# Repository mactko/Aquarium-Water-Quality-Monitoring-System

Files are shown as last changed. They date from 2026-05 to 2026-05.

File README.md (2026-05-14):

# 🐠 Aquarium Water Quality Monitor

An embedded system for continuous, automated monitoring and maintenance of aquarium water quality — measuring temperature and turbidity, controlling a pump/filter, and pushing data to the cloud.

---

## ✨ What It Does

| Feature | Details |
|---|---|
| 🌡️ Temperature | DS18B20 sensor via 1-Wire |
| 💧 Turbidity | SEN0189 analog sensor + median/deadzone filtering |
| ⚙️ Pump Control | Auto PWM regulation based on turbidity |
| 📡 Connectivity | Wi-Fi with auto-reconnect (FreeRTOS) |
| ☁️ Cloud | Sensor data → Azure Table Storage via MQTT over TLS |

---

## 🔧 Hardware

- **ESP32-DevKitC** — main microcontroller (Wi-Fi, dual-core)
- **DS18B20** — waterproof digital temperature sensor
- **SEN0189** — analog turbidity sensor (DF Robot)
- **DC water pump** — MOSFET-switched, PWM-controlled
- **4-stage filter** — mechanical filtration driven by the pump
- **12V adapter** + **5V regulator** — power supply chain

---

## 🖥️ System Overview

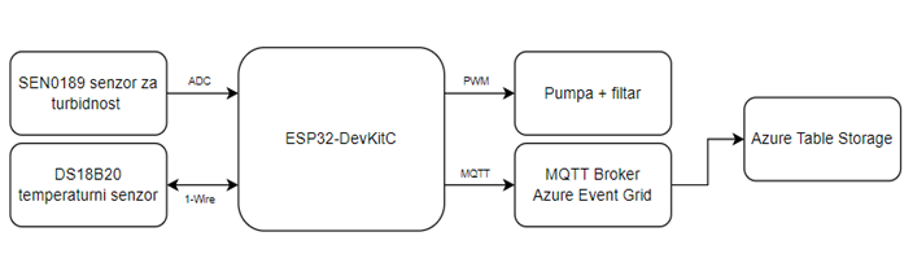
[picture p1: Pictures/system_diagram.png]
System Block Diagram


---

## ☁️ Cloud Architecture

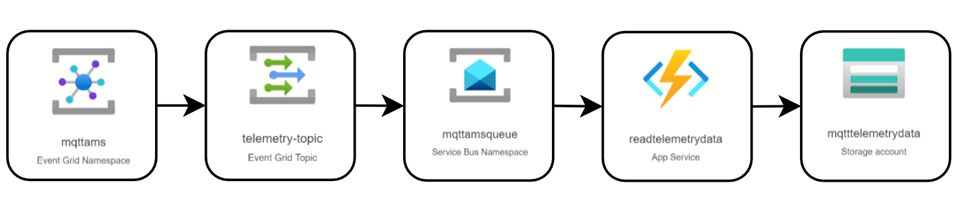
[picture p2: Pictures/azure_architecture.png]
Azure Cloud Architecture


```
ESP32 → MQTT/TLS → Azure Event Grid → Service Bus Queue → Function App → Table Storage
```

Telemetry is published every 60 seconds in the format:
```
<temperature>|<turbidity>    e.g. 27.500000|234
```

---

## 🚀 Quick Start

1. **Install** [ESP-IDF v5.x](https://docs.espressif.com/projects/esp-idf/en/stable/esp32/get-started/)
2. **Provision Azure** — Event Grid Namespace, Service Bus, Function App, Table Storage
3. **Generate TLS certs** with OpenSSL and place them in `Code/ESP/main/certificates/` and `Code/ESP/main/keys/`
4. **Configure** Wi-Fi credentials and MQTT broker via `idf.py menuconfig`
5. **Build & flash:**
```bash
cd "Code/ESP"
idf.py build
idf.py -p <PORT> flash monitor
```

---

## 📁 Project Structure

```
├── Code/
│   ├── ESP/               # ESP32 firmware (ESP-IDF)
│   │   ├── components/    # Drivers: Wi-Fi, DS18B20, pump, turbidity
│   │   └── main/          # App entry point + TLS certs/keys
│   └── Azure/             # Function App — Service Bus consumer → Table Storage
├── 3d models/             # 3D-printed enclosure
├── Pictures/              # Images and diagrams
└── README.md
```

---

## 🧪 Test Results

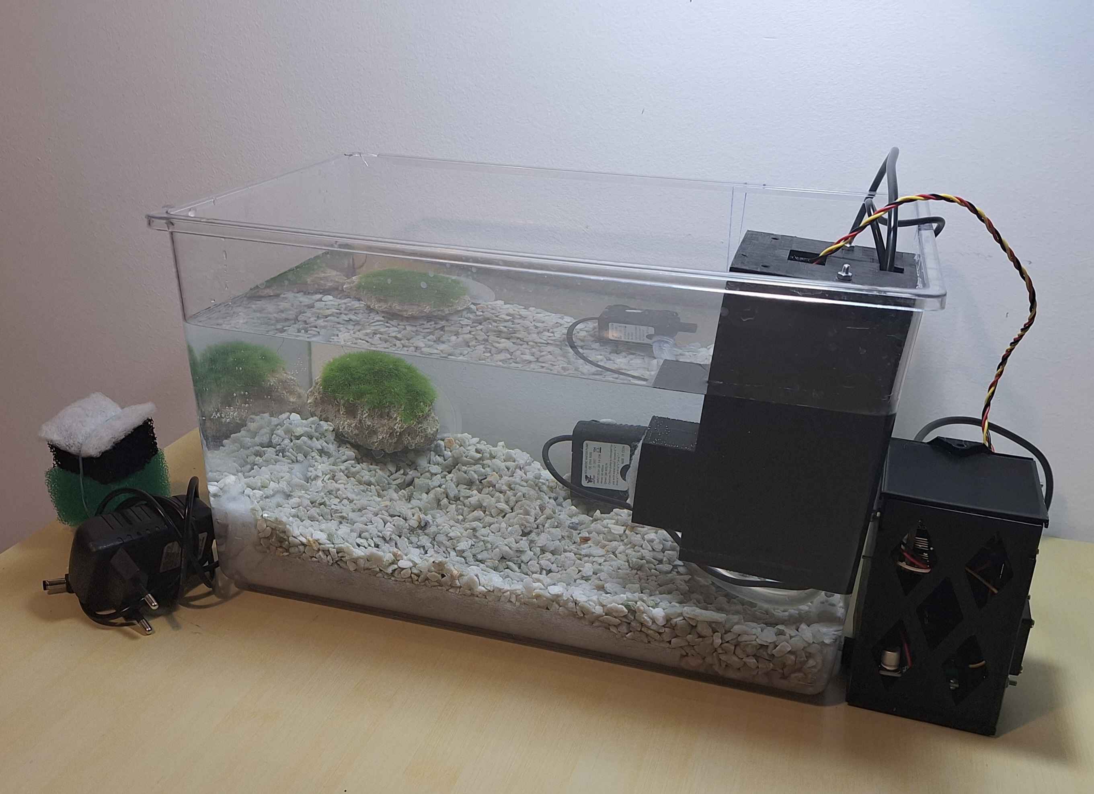
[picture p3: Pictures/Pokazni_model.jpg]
Test Setup


Tested continuously for **12 hours** on a small acrylic aquarium:

- ✅ Data successfully uploaded every 60 s throughout
- ✅ Auto-recovery from Wi-Fi and MQTT disconnections
- ✅ Median + deadzone filter effectively suppressed sensor noise
- ⚠️ Gradual turbidity drift due to sedimentation — periodic sensor cleaning recommended

---

## 🛠️ Common Issues

| Issue | Fix |
|---|---|
| Won't connect to Wi-Fi | Check SSID/password in config |
| MQTT refused | Regenerate certs; re-register device in Azure |
| Turbidity reads 0 | Check wiring to GPIO33; confirm sensor is submerged |
| Temperature reads 85°C | Check pull-up resistor on 1-Wire data line |
| No data in Table Storage | Check Service Bus backlog; review Function App logs |

---

*Developed as an undergraduate thesis at the Faculty of Electrical Engineering and Computing, University of Zagreb.*

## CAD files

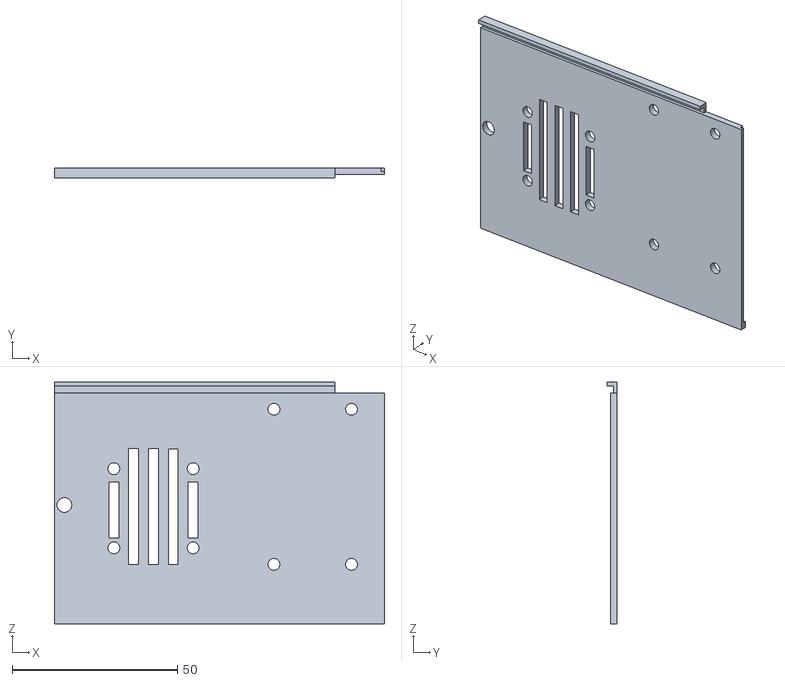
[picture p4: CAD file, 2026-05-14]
3d models/Control unit/Left_panel.stl
100.0 x 3.00 x 73.2

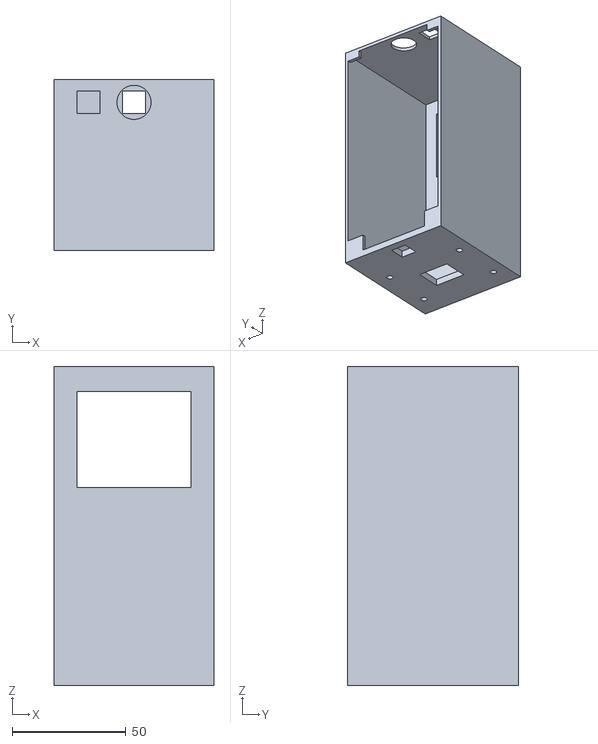
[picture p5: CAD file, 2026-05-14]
3d models/Housing/Housing.stl
70.0 x 75.0 x 140.0

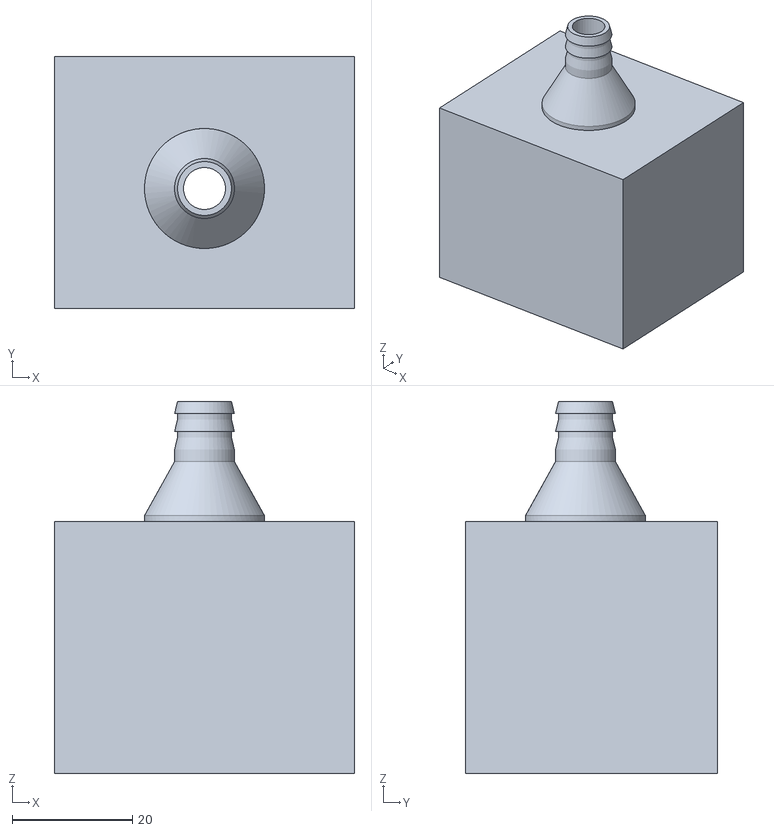
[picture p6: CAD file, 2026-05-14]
3d models/Housing/Filter.stl
50.0 x 42.0 x 62.0

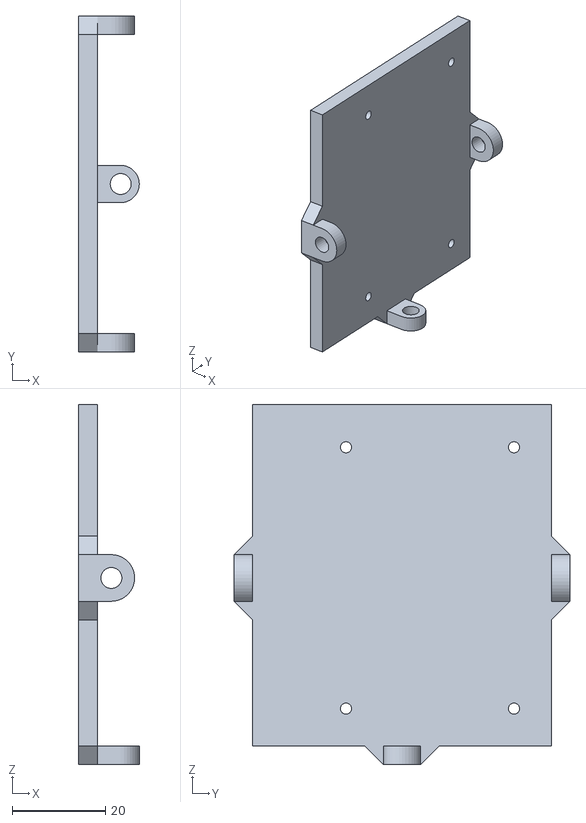
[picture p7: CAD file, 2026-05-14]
3d models/Control unit/Bottom_panel.stl
13.0 x 72.0 x 77.2

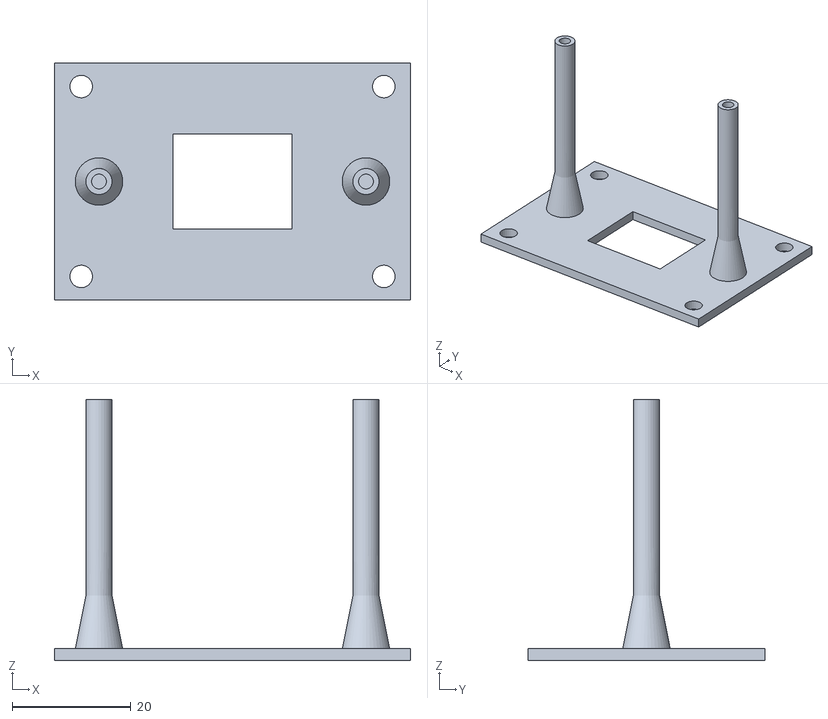
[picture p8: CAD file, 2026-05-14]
3d models/Housing/SEN0189_sensor_holder.stl
60.0 x 40.0 x 44.0

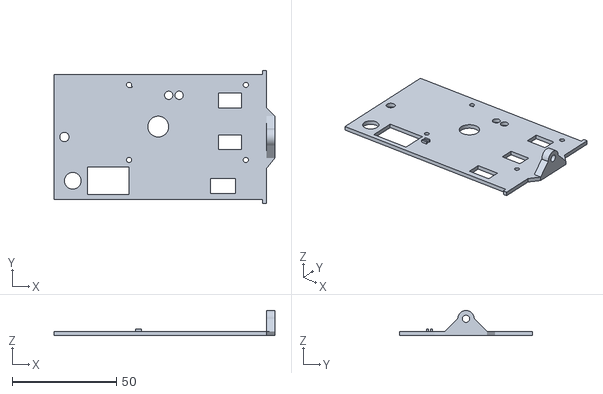
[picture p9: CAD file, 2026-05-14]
3d models/Control unit/Back_panel.stl
106.0 x 64.0 x 12.0

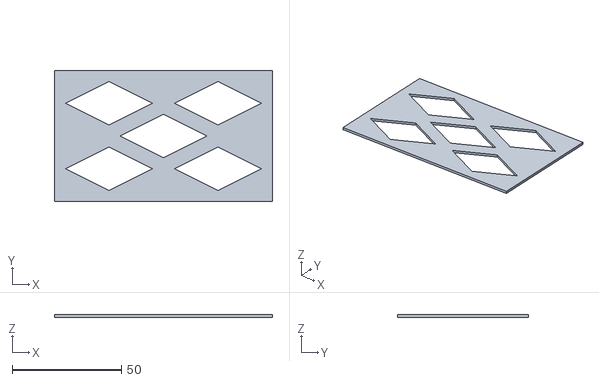
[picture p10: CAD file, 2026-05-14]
3d models/Control unit/Forward_panel.stl
100.0 x 60.0 x 1.20

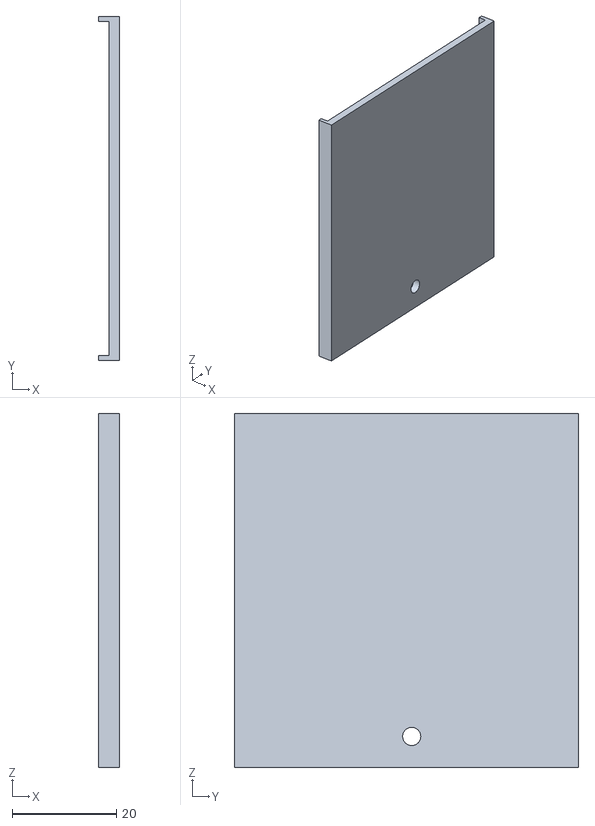
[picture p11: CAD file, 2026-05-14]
3d models/Control unit/Top_panel.stl
4.00 x 66.0 x 68.0

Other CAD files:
3d models/Control unit/Right_panel.stl

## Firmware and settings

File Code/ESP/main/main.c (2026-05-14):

#include "main.h"

static float temperature_data = 0;
static int turbidity_data = 0;

static const char *TAG = "MQTTS";

esp_mqtt_client_handle_t mqtt_client;

volatile uint8_t brokerC = 0;

extern const uint8_t brokerCert_pem_start[] asm("_binary_brokerCert_pem_start");
extern const uint8_t brokerCert_pem_end[] asm("_binary_brokerCert_pem_end");

extern const uint8_t deviceCert_pem_start[] asm("_binary_deviceCert_pem_start");
extern const uint8_t deviceCert_pem_end[] asm("_binary_deviceCert_pem_end");

extern const uint8_t deviceCert_key_start[] asm("_binary_deviceCert_key_start");
extern const uint8_t deviceCert_key_end[] asm("_binary_deviceCert_key_end");

void mqtt_event_handler(void *handler_args, esp_event_base_t base, int32_t event_id, void *event_data)
{
    esp_mqtt_event_handle_t event = event_data;

    switch ((esp_mqtt_event_id_t)event_id) {
    case MQTT_EVENT_CONNECTED:
        ESP_LOGI(TAG, "Connected to broker");
        esp_mqtt_client_publish(mqtt_client, "telemetry/my-device/temperature", "0.0|0", 0, 1, 0); 
        break;
    case MQTT_EVENT_DISCONNECTED:
        ESP_LOGI(TAG, "MQTT_EVENT_DISCONNECTED");
        break;
    case MQTT_EVENT_SUBSCRIBED:
        ESP_LOGI(TAG, "MQTT_EVENT_SUBSCRIBED, msg_id=%d", event->msg_id);
        break;
    case MQTT_EVENT_UNSUBSCRIBED:
        ESP_LOGI(TAG, "MQTT_EVENT_UNSUBSCRIBED, msg_id=%d", event->msg_id);
        break;
    case MQTT_EVENT_PUBLISHED:
        ESP_LOGI(TAG, "Recieved PUBACK/PUBCOMP -> Test reached broker");
        brokerC = 1;
        break;
    case MQTT_EVENT_DATA:
        ESP_LOGI(TAG, "MQTT_EVENT_DATA");
        break;
    case MQTT_EVENT_ERROR:
        ESP_LOGI(TAG, "MQTT_EVENT_ERROR");  
        brokerC = 0;  
        break;
    default:
        ESP_LOGI(TAG, "Other event id:%d", event->event_id);
        break;
    }
}

esp_err_t mqtt_app_start(void)
{
    const esp_mqtt_client_config_t mqtt_cfg = {
        .broker = {
            .address = {
                .uri = "uri",
            },
            .verification = {
                .certificate = (char *)brokerCert_pem_start,
                .certificate_len = GetBrokerCertLength()
            },
        },
        .credentials = {
            .username = "ESP32-node",
            .authentication = {
                .certificate = (char *)deviceCert_pem_start,
                .certificate_len = GetDeviceCertLength(),
                .key = (char *)deviceCert_key_start,
                .key_len = GetDeviceKeyLength()
            }
        }
    };

    mqtt_client = esp_mqtt_client_init(&mqtt_cfg);
    if(mqtt_client == NULL){
        ESP_LOGI(TAG, "Failed MQTT client initilization ...");
        return ESP_FAIL;
    }
    esp_mqtt_client_register_event(mqtt_client, ESP_EVENT_ANY_ID, mqtt_event_handler, NULL);
    esp_mqtt_client_start(mqtt_client);

    return ESP_OK;
}

static void send_telemetry_data(TURBIDITY_reading *turbidity, DS18B20_reading *temperature){
    uint16_t length_temp = snprintf(NULL, 0, "%f", temperature->reading) + snprintf(NULL, 0, "%d", turbidity->reading) + 1 + 1;

    //ESP_LOGI("LIST: ", "list size is %d", length_temp);
    ESP_LOGI(TAG, "Temperature:  %f, Turbidity: %d", temperature->reading, turbidity->reading);
    char data_string[length_temp]; 

    sprintf(data_string, "%f|%d", temperature->reading, turbidity->reading);

    esp_mqtt_client_publish(mqtt_client, "telemetry/my-device/temperature", data_string, 0, 0, 0); 
}

void wait_mqtt(){
    do{
        vTaskDelay(500);
    } while(brokerC == 0);
}

static uint32_t GetBrokerCertLength(){
    return brokerCert_pem_end - brokerCert_pem_start;
}
static uint32_t GetDeviceCertLength(){
    return deviceCert_pem_end - deviceCert_pem_start;
}
static uint32_t GetDeviceKeyLength(){
    return deviceCert_key_end - deviceCert_key_start;
}

void app_main(void)
{
    esp_err_t ret = ESP_OK;

    DS_Info ds18b20_sensor;
    TURBIDITY_reading turbidity;
    DS18B20_reading temperature;


    ESP_LOGI(TAG, "[APP] Startup..");
    ESP_LOGI(TAG, "[APP] Free memory: %" PRIu32 " bytes", esp_get_free_heap_size());
    ESP_LOGI(TAG, "[APP] IDF version: %s", esp_get_idf_version());

    ESP_ERROR_CHECK(nvs_flash_init());

    ESP_ERROR_CHECK(esp_netif_init());

    ESP_ERROR_CHECK(esp_event_loop_create_default());
    
    do {
        ret = init_DS(DS_PIN, &ds18b20_sensor);
    } while(ret != ESP_OK);
    
    
    ESP_ERROR_CHECK(turbidityInit(T_PIN));
    ESP_ERROR_CHECK(ledc_init());
    
    ESP_ERROR_CHECK(init_wifi());
    ESP_ERROR_CHECK(wait_wifi());
    ESP_ERROR_CHECK(mqtt_app_start());
    
    wait_mqtt();

    while(1){
        
        do{
            temperature = get_temp_DS(&ds18b20_sensor);
        } while(temperature.status != ESP_OK);
        ESP_LOGI("TEMP: ", "%f", temperature.reading);
        
        do{
            turbidityRead(&turbidity);
        } while(turbidity.status != ESP_OK);
        ESP_LOGI("TURBIDITY: ", "%d", turbidity.reading); 
        
        if(check_wifi() != 0 ) {
            send_telemetry_data(&turbidity, &temperature);
        }   

        pump_control(turbidity.reading);

        vTaskDelay(pdMS_TO_TICKS(120000));
    }
}

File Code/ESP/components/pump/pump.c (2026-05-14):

#include "pump.h"

#define PUMP_CHANNEL LEDC_CHANNEL_0
#define PUMP_TIMER LEDC_TIMER_1
#define PUMP_GPIO GPIO_NUM_18
#define PUMP_MIN_DUTY (3072) //(1024)
#define PUMP_MID_DUTY (3584)
#define PUMP_MAX_DUTY (4096)
#define PUMP_FADE_TIME (1000)
#define HIST 10

static ledc_timer_config_t pump_config;

void pump_control(int turbidity){

    if (turbidity > 80) {
        ledc_set_fade_with_time(LEDC_HIGH_SPEED_MODE, PUMP_CHANNEL, PUMP_MAX_DUTY, PUMP_FADE_TIME);
    } else if(turbidity > 30){
        ledc_set_fade_with_time(LEDC_HIGH_SPEED_MODE, PUMP_CHANNEL, PUMP_MID_DUTY, PUMP_FADE_TIME);
    } else if(turbidity < 30) {
        ledc_set_fade_with_time(LEDC_HIGH_SPEED_MODE, PUMP_CHANNEL, PUMP_MIN_DUTY, PUMP_FADE_TIME);
    } 

    ledc_fade_start(LEDC_HIGH_SPEED_MODE, PUMP_CHANNEL, LEDC_FADE_NO_WAIT);
}

esp_err_t ledc_init()
{
    
    pump_config.duty_resolution = LEDC_TIMER_12_BIT;
    pump_config.freq_hz = 1000;
    pump_config.speed_mode = LEDC_HIGH_SPEED_MODE;
    pump_config.timer_num = PUMP_TIMER;
    pump_config.clk_cfg = LEDC_USE_APB_CLK;

    if (ledc_timer_config(&pump_config) != ESP_OK) return ESP_FAIL;

    ledc_channel_config_t pump_channel_config  = {
        .channel = PUMP_CHANNEL,
        .duty = PUMP_MIN_DUTY,
        .gpio_num = PUMP_GPIO,
        .speed_mode = LEDC_HIGH_SPEED_MODE,
        .hpoint = 0,
        .timer_sel = PUMP_TIMER,
        .flags.output_invert = 0,
    };

    if (ledc_channel_config(&pump_channel_config) != ESP_OK) return ESP_FAIL;

    if (ledc_fade_func_install(0) != ESP_OK) return ESP_FAIL;

    return ESP_OK;
}
